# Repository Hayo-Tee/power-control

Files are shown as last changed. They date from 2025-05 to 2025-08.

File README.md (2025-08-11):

# Power Control PC by ESP32

[🇷🇺 RU](README_ru.md) | [🇬🇧 EN](README.md)

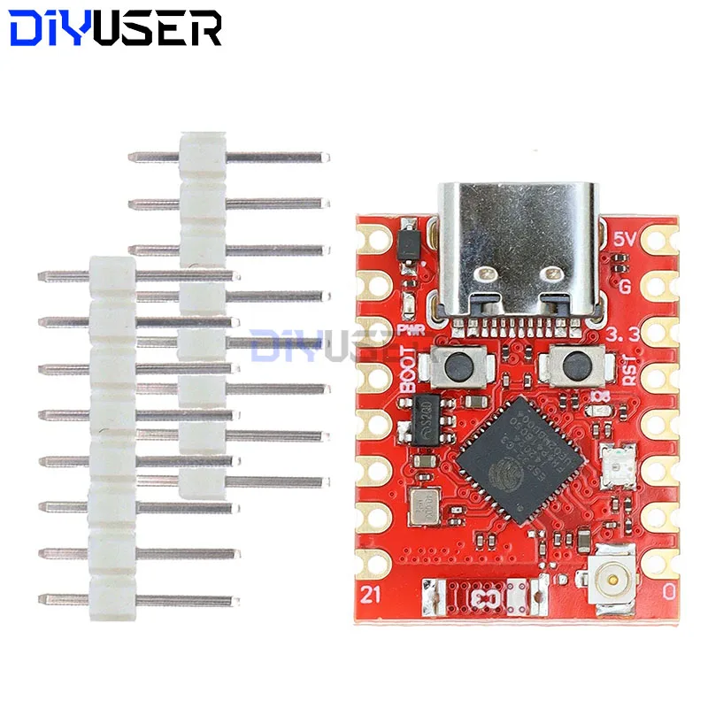
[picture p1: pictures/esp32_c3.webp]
ESP32-C3


## Project Description

Recently, I purchased a **Cooler Master Stacker 830** case and built a server PC based on the **ASUS Z10PE-D8** motherboard. Since I access the server via **Tailscale**, I faced a challenge — how to power on the PC remotely if it is completely turned off at home. There are many solutions available online, but I decided to create my own using **ESPHome** and **ESP32-C3**.

---

## Key Features

* **Power on the PC**
* **Power off the PC**
* **Force shutdown** (emulation of holding the power button)
* **Restart the PC**
* **Get PC status** (on / off)

---

## Additional Functionality for Unraid

Since my server runs **Unraid OS**, I added an extra button to control a virtual machine. You can easily repurpose this feature for any other task by modifying the script.

* **Single press** — starts the virtual machine
* **Double press** — stops the virtual machine
* **Long press** — force stops the virtual machine

---

## License

This project is distributed under the **MIT** license.

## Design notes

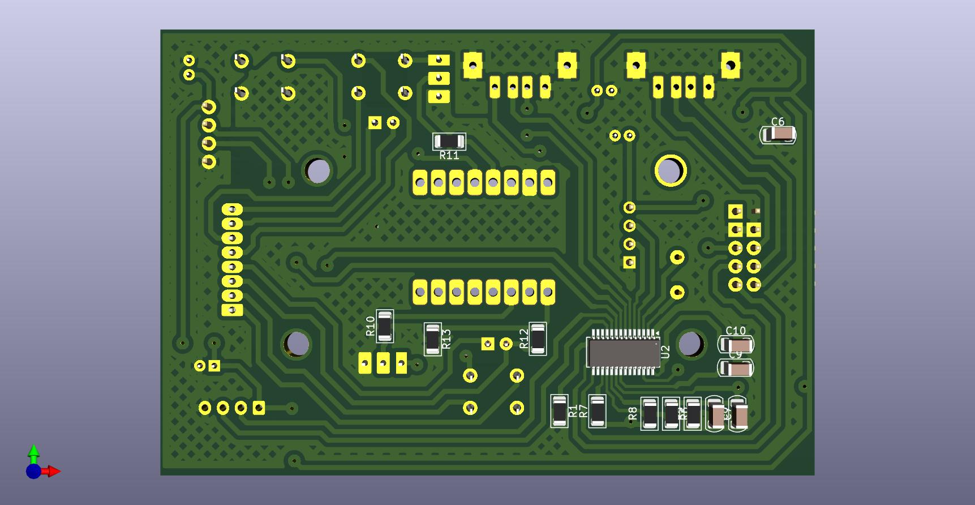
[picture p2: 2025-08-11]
pictures/power-control_1.jpg

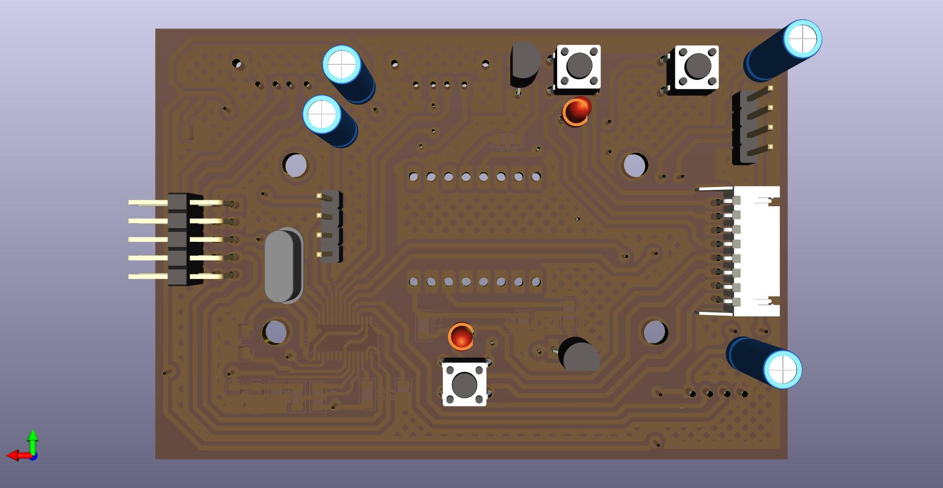
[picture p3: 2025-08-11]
pictures/power-control_2.jpg

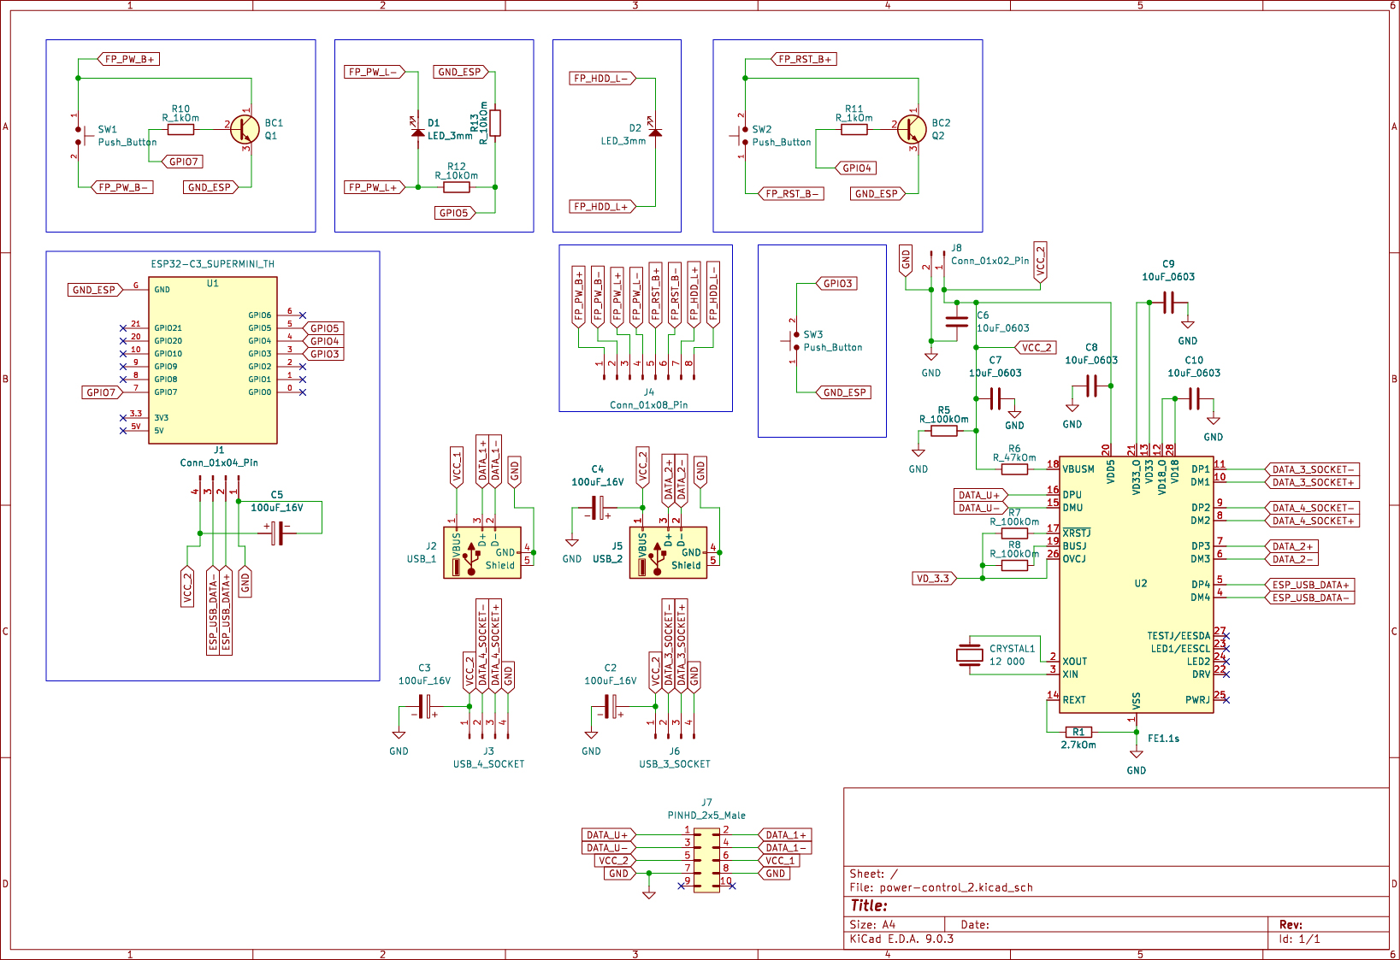
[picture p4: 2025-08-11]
pictures/power-control_scheme.jpg

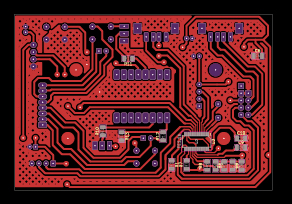
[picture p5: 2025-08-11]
pictures/power-control_pcb.jpg

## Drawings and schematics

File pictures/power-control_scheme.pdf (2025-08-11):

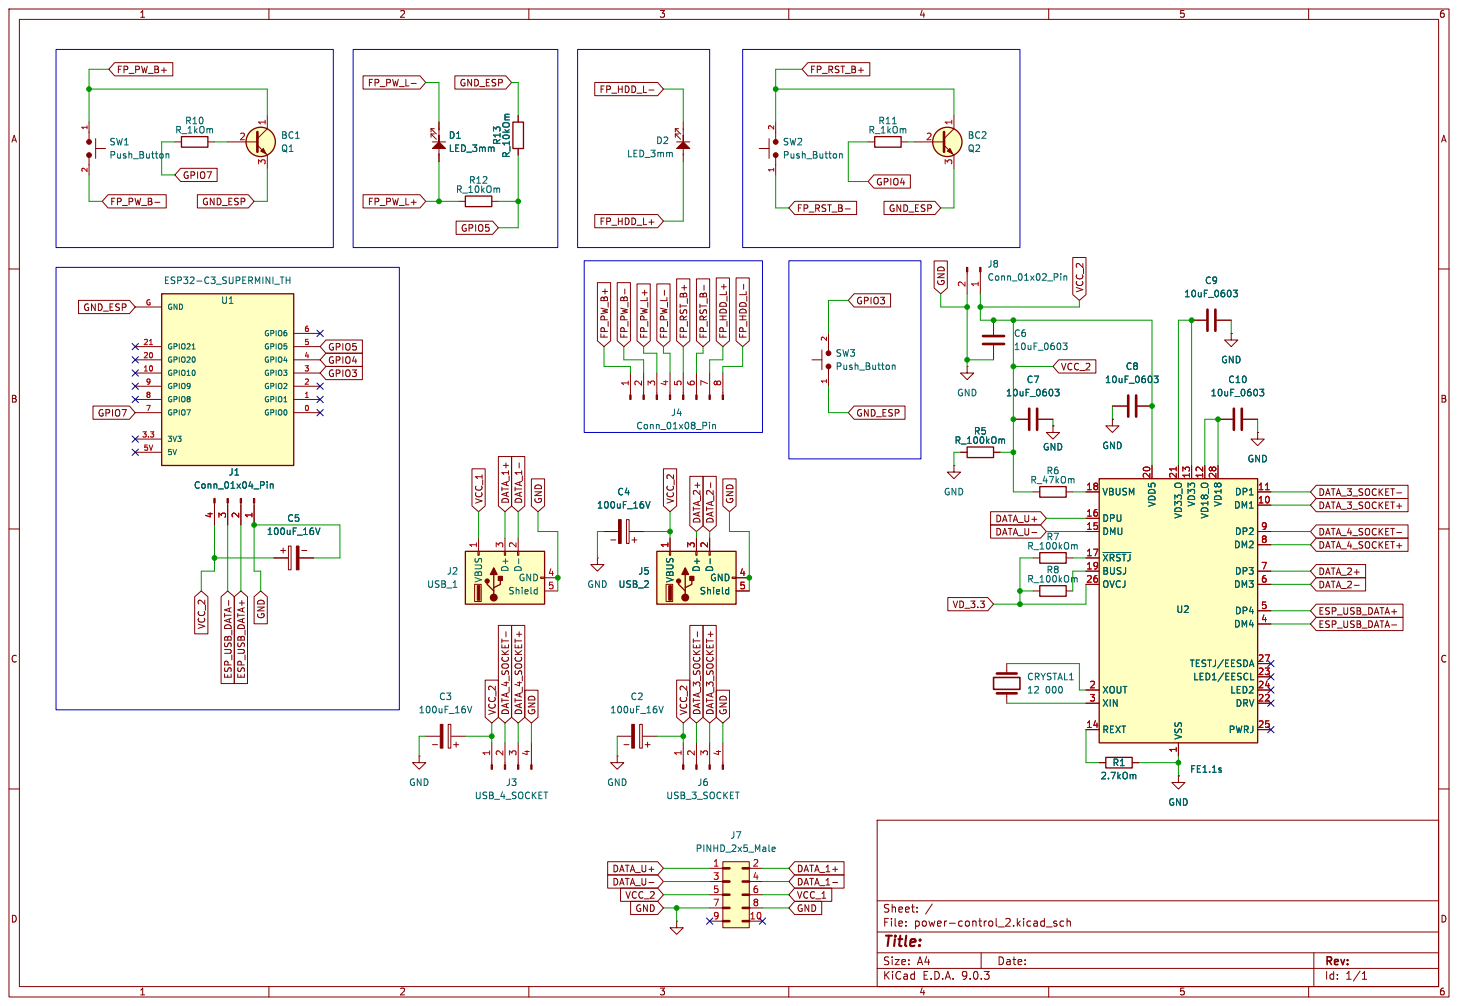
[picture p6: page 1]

Id: 1/1 Title: File: power-control_2.kicad_sch Sheet: /

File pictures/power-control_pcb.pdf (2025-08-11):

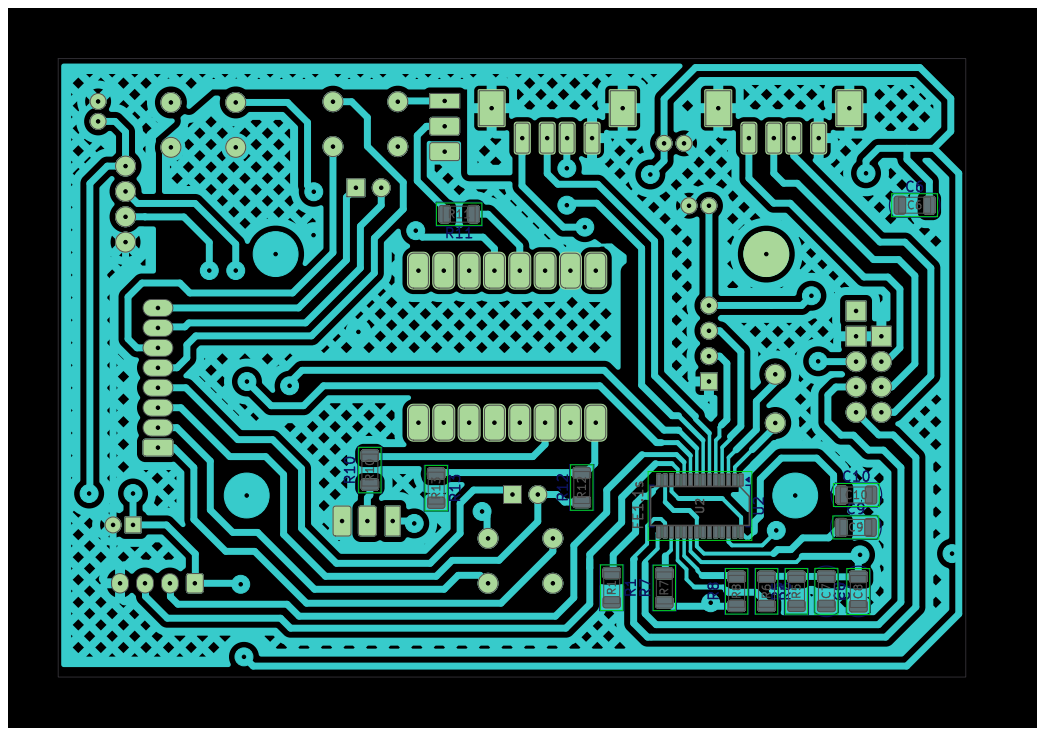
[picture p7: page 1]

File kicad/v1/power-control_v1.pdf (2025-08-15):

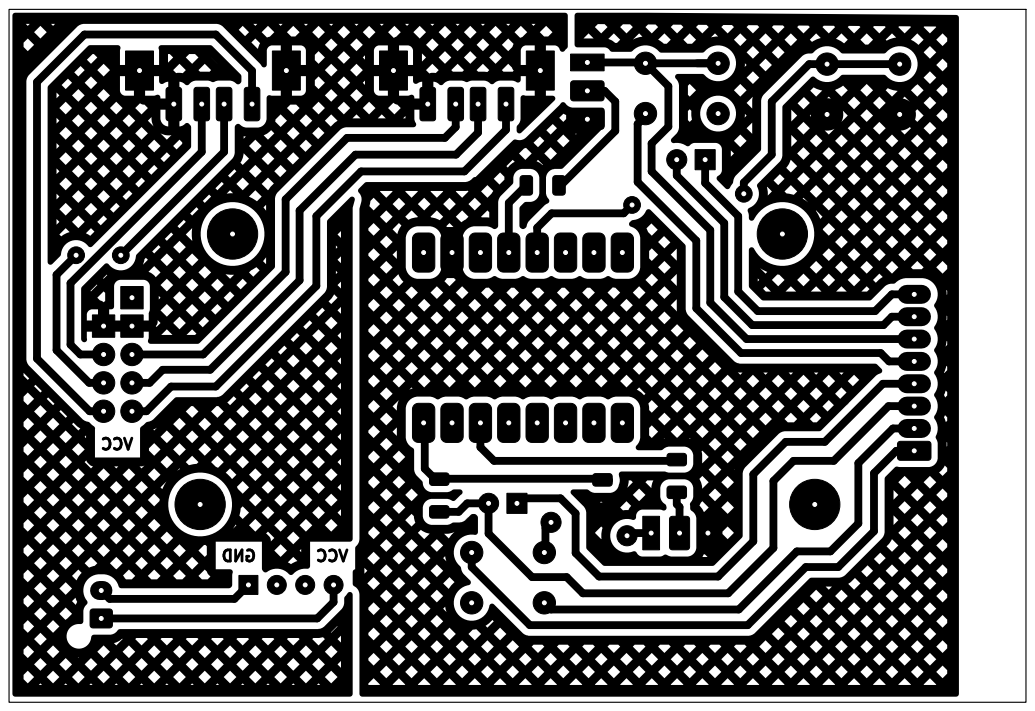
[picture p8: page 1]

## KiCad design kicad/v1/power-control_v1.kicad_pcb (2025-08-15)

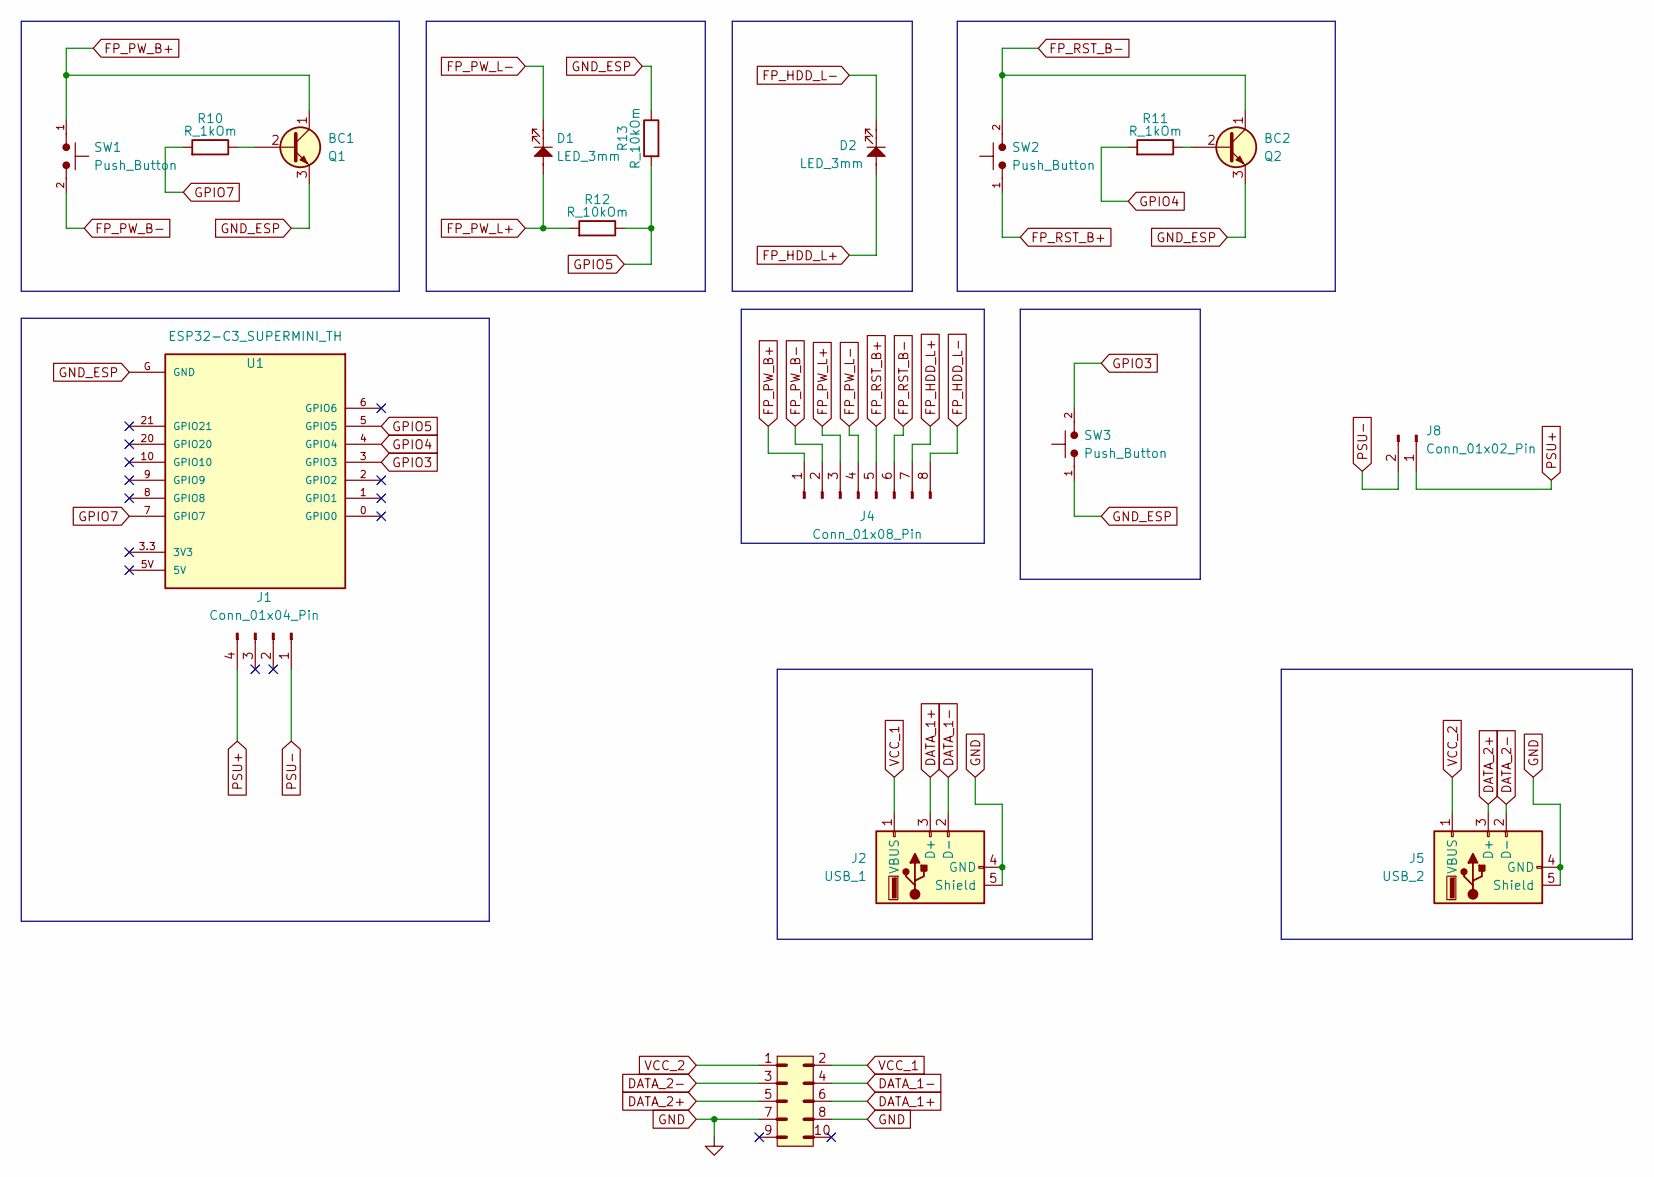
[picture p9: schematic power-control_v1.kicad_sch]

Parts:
BC1: Q1; TO-92_Inline_Wide_CBE
BC2: Q2; TO-92_Inline_Wide_CBE
D1, D2: LED_3mm; LED_D3.0mm
J1: Conn_01x04_Pin; PinHeader_1x04_P2.54mm_Vertical
J2: USB_1; ONSHORE_USB-A1VSB6
J4: Conn_01x08_Pin; Connector_MB_FP
J5: USB_2; ONSHORE_USB-A1VSB6
J7: PINHD_2x5_Male; PinHeader_2x05_P2.54mm_Horizontal
J8: Conn_01x02_Pin; JST_XH_B2B-XH-AM_1x02_P2.50mm_Vertical
R10, R11: R_1kOm; R_1206_3216Metric
R12, R13: R_10kOm; R_1206_3216Metric
SW1, SW2, SW3: Push_Button; SW_PUSH_6mm
U1: ESP32-C3_SUPERMINI_TH; MODULE_ESP32-C3_SUPERMINI

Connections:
DATA_1+: J2.3 (D+), J7.6
DATA_1-: J2.2 (D-), J7.4
DATA_2+: J5.3 (D+), J7.5
DATA_2-: J5.2 (D-), J7.3
FP_HDD_L+: D2.2, J4.7
FP_HDD_L-: D2.1, J4.8
FP_PW_B+: BC1.1 (C), J4.1, SW1.1
FP_PW_B-: J4.2, SW1.2
FP_PW_L+: D1.2, J4.3, R12.1
FP_PW_L-: D1.1, J4.4
FP_RST_B+: J4.5, SW2.1
FP_RST_B-: BC2.1 (C), J4.6, SW2.2
GND: J2.4 (GND), J2.5 (Shield), J2.S1, J2.S2, J5.4 (GND), J5.5 (Shield), J5.S1, J5.S2, J7.7, J7.8
GND_ESP: BC1.3 (E), BC2.3 (E), R13.2, SW3.1, U1.G (GND)
GPIO3: SW3.2, U1.3 (GPIO3)
GPIO4: R11.1, U1.4 (GPIO4)
GPIO5: R12.2, R13.1, U1.5 (GPIO5)
GPIO7: R10.1, U1.7 (GPIO7)
unnamed: BC1.2 (B), R10.2
unnamed: BC2.2 (B), R11.2
PSU+: J1.4, J8.1
PSU-: J1.1, J8.2
VCC_1: J2.1 (VBUS), J7.2
VCC_2: J5.1 (VBUS), J7.1

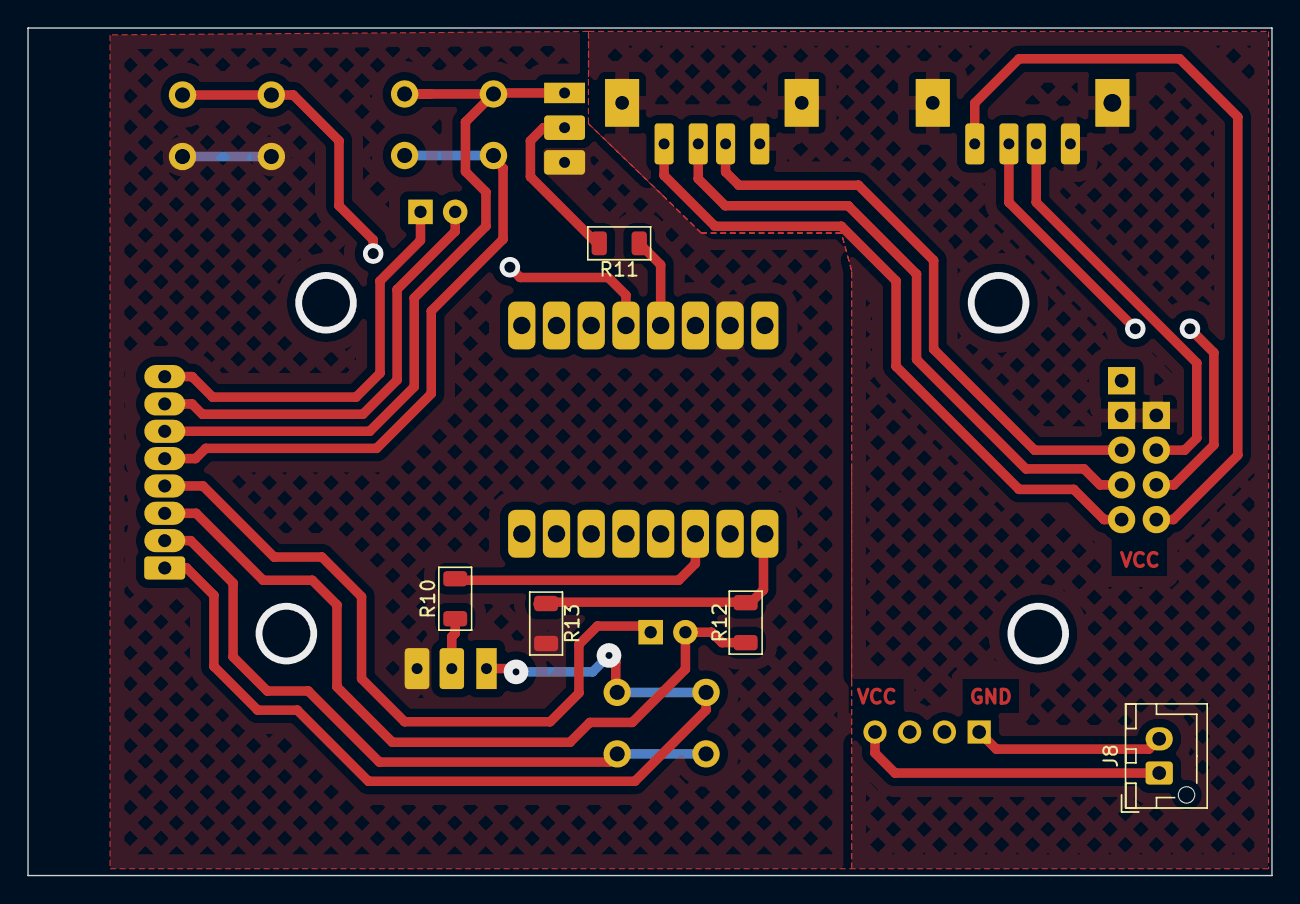
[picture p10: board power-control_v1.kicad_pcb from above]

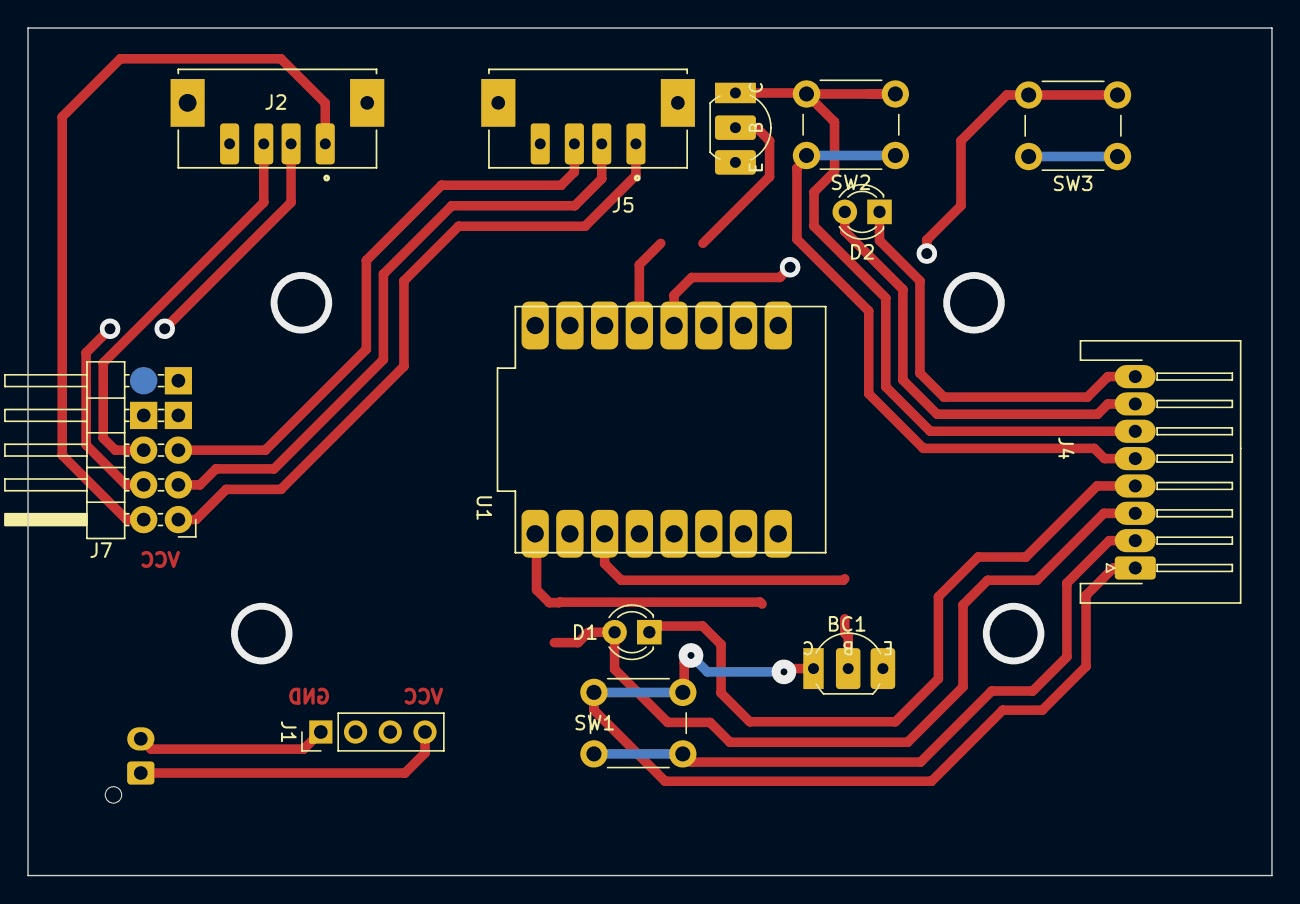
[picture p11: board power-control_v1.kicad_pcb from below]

Board: 2 copper layers, 91.0 x 62.0 mm, 18 parts (13 on the bottom side), 24 nets.

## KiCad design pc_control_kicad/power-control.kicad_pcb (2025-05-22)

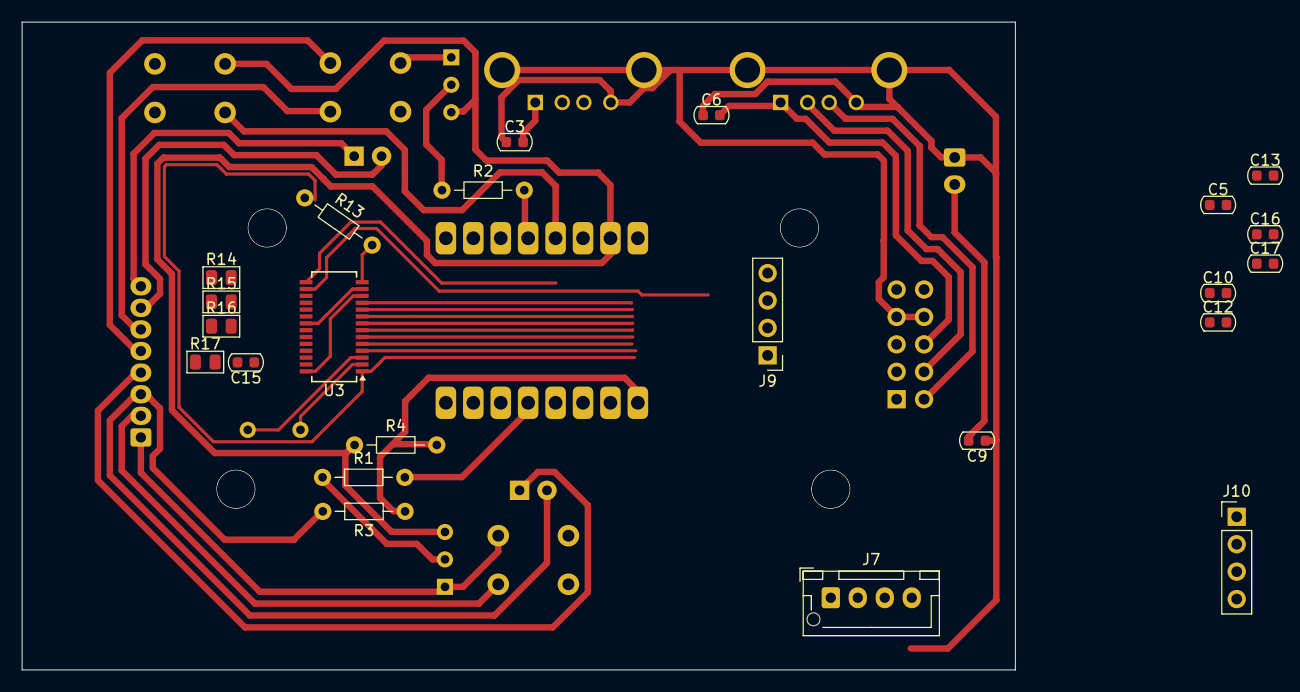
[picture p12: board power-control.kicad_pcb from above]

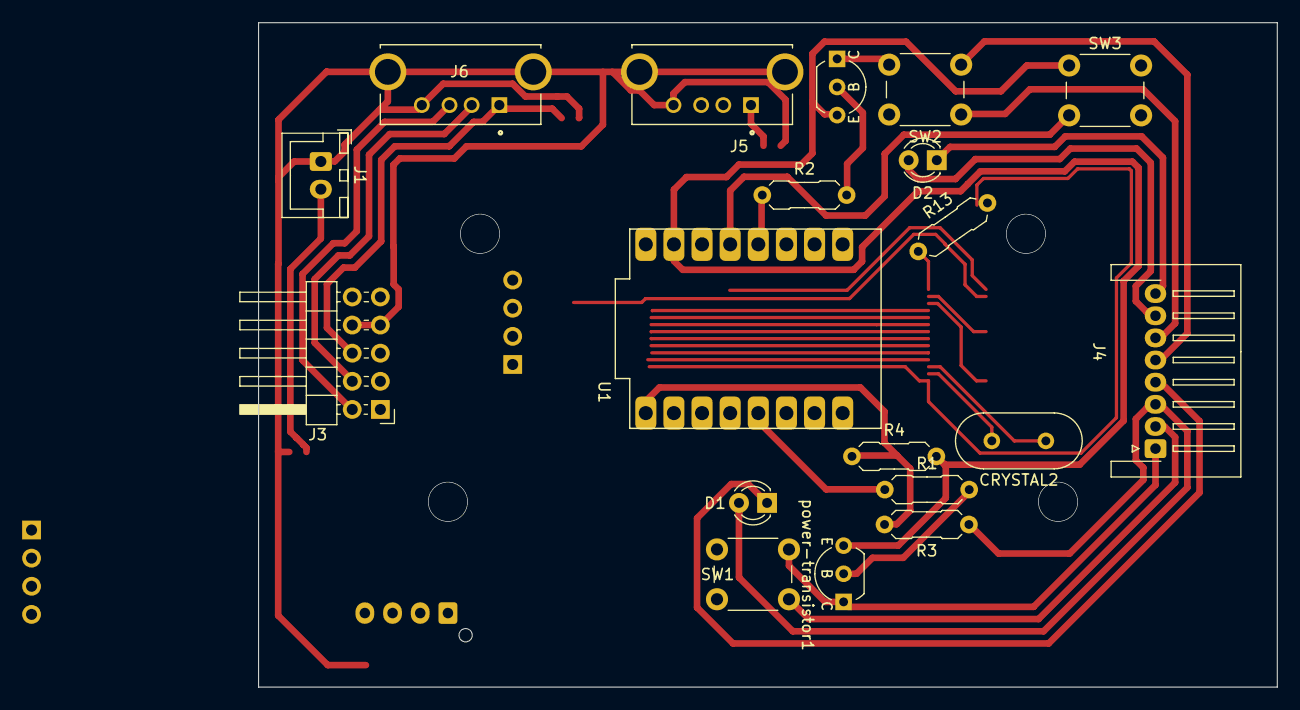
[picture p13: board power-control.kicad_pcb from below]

Board: 2 copper layers, 92.0 x 60.0 mm, 37 parts (19 on the bottom side), 39 nets.

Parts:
C3, C5, C6, C10, C12: 100uF_0603; C_0603_1608Metric
C9, C13, C15, C16, C17: 10uF_0603; C_0603_1608Metric
CRYSTAL2: 12 000; Crystal_HC49-4H_Vertical
D1, D2: LED_3mm; LED_D3.0mm
J1: PSU_POWER; JST_XH_B2B-XH-A_1x02_P2.50mm_Vertical
J3: PINHD_2x5_Male; PinHeader_2x05_P2.54mm_Horizontal
J4: Conn_01x08_Pin; Connector_MB_FP
J5, J6: USB_A; ONSHORE_USB-A1VSB6
J7: USB_3_SOCKET; JST_XH_B4B-XH-AM_1x04_P2.50mm_Vertical
J9: Conn_01x04_Pin; PinHeader_1x04_P2.54mm_Vertical
J10: USB_4_SOCKET; PinHeader_1x04_P2.54mm_Vertical
R1, R2: 1kOm; R_Axial_DIN0207_L6.3mm_D2.5mm_P7.62mm_Horizontal
R3, R4: 10kOm; R_Axial_DIN0207_L6.3mm_D2.5mm_P7.62mm_Horizontal
R13: 2.7kOm; R_Axial_DIN0207_L6.3mm_D2.5mm_P7.62mm_Horizontal
R14, R15, R17: R_100kOm; R_0805_2012Metric
R16: R_47kOm; R_0805_2012Metric
SW1, SW2, SW3: Push_Button; SW_PUSH_6mm
U1: ESP32-C3_SUPERMINI_TH; MODULE_ESP32-C3_SUPERMINI
U3: FE1.1s; SSOP-28_3.9x9.9mm_P0.635mm
power-transistor1: BC548; TO-92_Inline_Wide_CBE
reset-transistor1: BC548; TO-92_Inline_Wide_CBE

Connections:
/DATA_1+: J3.2, J6.3 (D+)
/DATA_1-: J3.4, J6.2 (D-)
/DATA_2+: J5.3 (D+), U3.11 (DP1)
/DATA_2-: J5.2 (D-), U3.10 (DM1)
/DATA_3_SOCKET+: J7.3, U3.7 (DP3)
/DATA_3_SOCKET-: J7.2, U3.6 (DM3)
/DATA_4_SOCKET+: J10.3, U3.5 (DP4)
/DATA_4_SOCKET-: J10.2, U3.4 (DM4)
/DATA_U+: J3.1, U3.16 (DPU)
/DATA_U-: J3.3, U3.15 (DMU)
/ESP_USB_DATA+: J9.2, U3.9 (DP2)
/ESP_USB_DATA-: J9.3, U3.8 (DM2)
/FP_HDD_L+: D2.2, J4.7
/FP_HDD_L-: D2.1, J4.8
/FP_PW_B+: J4.1, SW1.1, power-transistor1.1 (C)
/FP_PW_B-: J4.2, SW1.2
/FP_PW_L+: D1.2, J4.3, R3.1 (+)
/FP_PW_L-: D1.1, J4.4
/FP_RST_B+: J4.5, SW2.2, reset-transistor1.1 (C)
/FP_RST_B-: J4.6, SW2.1
/GND_ESP: R4.2 (-), SW3.1, U1.G (GND), power-transistor1.3 (E), reset-transistor1.3 (E)
/GPIO3: R2.1 (+), U1.3 (GPIO3)
/GPIO4: SW3.2, U1.4 (GPIO4)
/GPIO5: R3.2 (-), R4.1 (+), U1.5 (GPIO5)
/GPIO9: R1.1 (+), U1.9 (GPIO9)
/VCC_1: C6.2, J3.6, J6.1 (VBUS)
/VCC_2: C3.2, C5.2, C9.2, C10.1, C12.2, C16.2, C17.1, J1.2, J3.5, J5.1 (VBUS), J7.1, J9.4, J10.1, R16.1, R17.2, U3.20 (VDD5)
/VD_3.3: R14.1, R15.1, U3.26 (OVCJ)
GND: C3.1, C5.1, C6.1, C9.1, C10.2, C12.1, C13.2, C15.2, C16.1, C17.2, J1.1, J3.7, J3.8, J5.4 (GND), J5.S1, J5.S2, J6.4 (GND), J6.S1, J6.S2, J7.4, J9.1, J10.4, R13.2, R17.1, U3.1 (VSS)
unnamed: R1.2 (-), power-transistor1.2 (B)
unnamed: R2.2 (-), reset-transistor1.2 (B)
unnamed: R15.2, U3.19 (BUSJ)
unnamed: R13.1, U3.14 (REXT)
unnamed: R16.2, U3.18 (VBUSM)
unnamed: C15.1, U3.12 (VD18_O), U3.28 (VD18)
unnamed: C13.1, U3.13 (VD33), U3.21 (VD33_O)
unnamed: CRYSTAL2.1, U3.3 (XIN)
unnamed: CRYSTAL2.2, U3.2 (XOUT)
unnamed: R14.2, U3.17 (~XRSTJ)

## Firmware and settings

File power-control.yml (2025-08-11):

substitutions:
  power_pin: GPIO7
  reboot_pin: GPIO4
  status_pin: GPIO5
  button_pin: GPIO3
  api_key: !secret power_control_api
  wifi_ssid: !secret wifi_ssid
  wifi_password: !secret wifi_password
  ap_password: !secret ap_password
  server_url: "http://server:8080"

esphome:
  name: pc-power-control
  friendly_name: "PC Power"
  platformio_options:
    build_flags:
      - '-DCONFIG_ESP_CONSOLE_USB_CDC=n'

esp32:
  board: esp32-c3-devkitm-1
  framework:
    type: arduino

uart:
  id: uart_bus
  tx_pin: GPIO21
  rx_pin: GPIO20
  baud_rate: 115200
  data_bits: 8
  parity: NONE
  stop_bits: 1

logger:
  level: DEBUG
  baud_rate: 115200
  logs:
    component.gpio: DEBUG
    multi_click: DEBUG

web_server:
  port: 80

ota:
  - platform: esphome
    password: 1507
  - platform: web_server

wifi:
  ssid: ${wifi_ssid}
  password: ${wifi_password}
  ap:
    ssid: "PC-Control-Fallback"
    password: ${ap_password}

http_request:
  useragent: esphome/pc-power-control
  timeout: 5s
  verify_ssl: false

output:
  - platform: gpio
    pin: ${power_pin}
    id: power_button_output
  - platform: gpio
    pin: ${reboot_pin}
    id: reboot_button_output

binary_sensor:
  - platform: gpio
    pin:
      number: ${status_pin}
      mode: input
    name: "PC Status"
    device_class: power
    id: pc_status

  - platform: gpio
    pin:
      number: ${button_pin}
      mode: INPUT_PULLUP
      inverted: true
    name: "Physical Button"
    id: physical_button
    internal: true
    filters:
      - delayed_on: 100ms  # Уменьшил задержку для более быстрого реагирования
      - delayed_off: 100ms
    on_multi_click:
      - timing:
          - ON for at most 0.3s  # Быстрое нажатие
          - OFF for at least 0.1s  # Минимальная пауза
          - ON for at most 0.3s  # Второе быстрое нажатие
          - OFF for at least 0.1s
        then:
          - logger.log: "Double press detected - stopping VM"
          - http_request.get:
              url: "${server_url}/stop_win.sh"
      - timing:
          - ON for at most 0.5s  # Одиночное нажатие
          - OFF for at least 0.3s
        then:
          - logger.log: "Single press detected - starting VM"
          - http_request.get:
              url: "${server_url}/start_win.sh"
      - timing:
          - ON for at least 4s  # Длинное нажатие (уменьшил время)
          - OFF for at least 0.3s
        then:
          - logger.log: "Long press detected - force stopping VM"
          - http_request.get:
              url: "${server_url}/destroy_win.sh"

sensor:
  - platform: uptime
    name: "Uptime"
  - platform: wifi_signal
    name: "WiFi Signal"
    update_interval: 60s

text_sensor:
  - platform: wifi_info
    ip_address:
      name: "IP Address"

button:
  - platform: template
    name: "Turn On PC"
    icon: "mdi:power"
    entity_category: "config"
    on_press:
      if:
        condition:
          binary_sensor.is_off: pc_status
        then:
          - output.turn_on: power_button_output
          - delay: 500ms
          - output.turn_off: power_button_output
          - http_request.get:
              url: "${server_url}/start_win.sh"

  - platform: template
    name: "Soft Shutdown PC"
    icon: "mdi:power-standby"
    entity_category: "config"
    on_press:
      if:
        condition:
          binary_sensor.is_on: pc_status
        then:
          - http_request.get:
              url: "${server_url}/stop_win.sh"
          - delay: 5s
          - output.turn_on: power_button_output
          - delay: 1s
          - output.turn_off: power_button_output

  - platform: template
    name: "Force Shutdown PC"
    icon: "mdi:power-off"
    entity_category: "config"
    on_press:
      if:
        condition:
          binary_sensor.is_on: pc_status
        then:
          - http_request.get:
              url: "${server_url}/destroy_win.sh"
          - delay: 5s
          - output.turn_on: power_button_output
          - delay: 5s
          - output.turn_off: power_button_output

  - platform: template
    name: "Reboot PC"
    icon: "mdi:restart-alert"
    entity_category: "config"
    on_press:
      - output.turn_on: reboot_button_output
      - delay: 500ms
      - output.turn_off: reboot_button_output

  - platform: template
    name: "Start VM"
    icon: "mdi:server"
    entity_category: "config"
    on_press:
      - http_request.get:
          url: "${server_url}/start_win.sh"

  - platform: template
    name: "Stop VM"
    icon: "mdi:server-off"
    entity_category: "config"
    on_press:
      - http_request.get:
          url: "${server_url}/stop_win.sh"

  - platform: template
    name: "Force Stop VM"
    icon: "mdi:server-remove"
    entity_category: "config"
    on_press:
      - http_request.get:
          url: "${server_url}/destroy_win.sh"

interval:
  - interval: 6h
    then:
      - logger.log: "Scheduled ESP32 restart (every 6 hours)"
      - lambda: |-
          ESP.restart();

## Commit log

2025-03-19 Update pc_control.yaml
    Power button and reset working
2025-08-11 full update
    [power-control_2.kicad_pcb, power-control_2.kicad_sch]
2025-08-11 update 3
    [power-control_2.kicad_sch]
2025-08-11 update 4
    [power-control_2.kicad_pcb]
2025-08-12 update 5
    [power-control_2.kicad_pcb, power-control_2.kicad_sch, power-control_v1.kicad_pcb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]
2025-08-15 update 6
    [power-control_v1.kicad_pcb, power-control_v1.kicad_sch]
2025-08-18 Photo of PCB
